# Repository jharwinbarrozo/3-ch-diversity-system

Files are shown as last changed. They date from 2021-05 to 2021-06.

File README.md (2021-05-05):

This is an Arduino code for a Wemos D1 board (ESP8266 chip), coupled to 3 LM1881 video sync separators, and a MAX4545 video switch.
Compared to the popular RSSI-based systems, the advantages a video-based diversity are:
- No need to open the receivers to get the RSSI [Receiver Signal Strength indication] signals. You just have to plug in your different receivers, and they can be of different types.
- There is no need to calibrate the RSSi signals of the different receivers (this is often the tricky part).
- It is also frequent to get a strongly distorted image, while the RSSI is high.
- When the reception level is low (flying far for instance), some receivers have RSSI close to zero, although the image is still viewable. In that case an RSSI-based system is not really efficient.

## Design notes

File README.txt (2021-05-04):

l1m          = Top layer
l2m          = Bottom layer
ss1          = Top silkscreen
sm1          = Top soldermask
sm2          = Bottom soldermask
outline      = Board outline
drill        = Plated holes Excellon file
drillnpt     = Non-Plated holes Excellon file
XYRS.csv     = Parts placement file
pcb.cad      = PCBWeb Project file

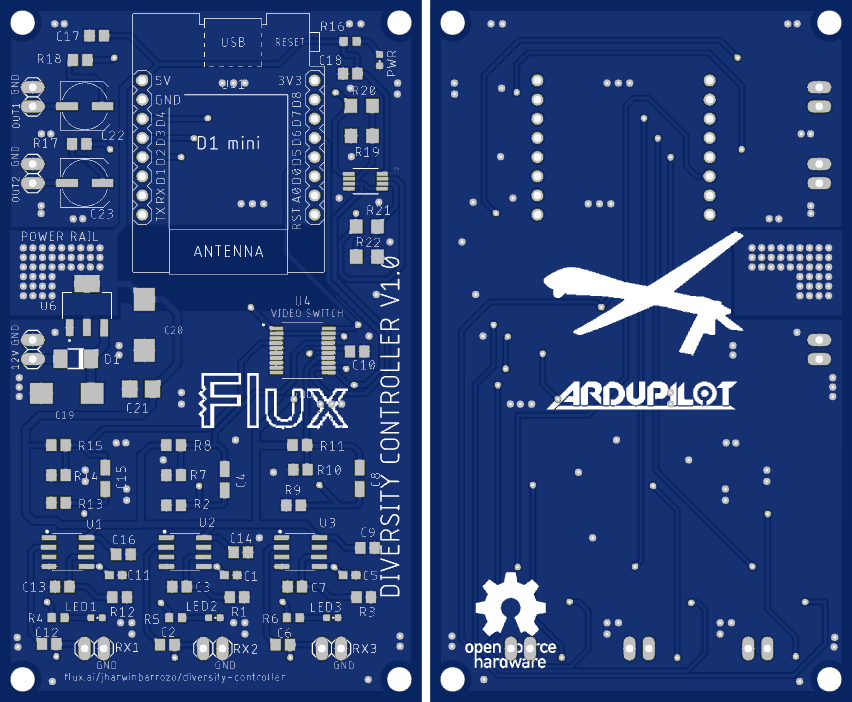
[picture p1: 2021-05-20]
board-preview.png

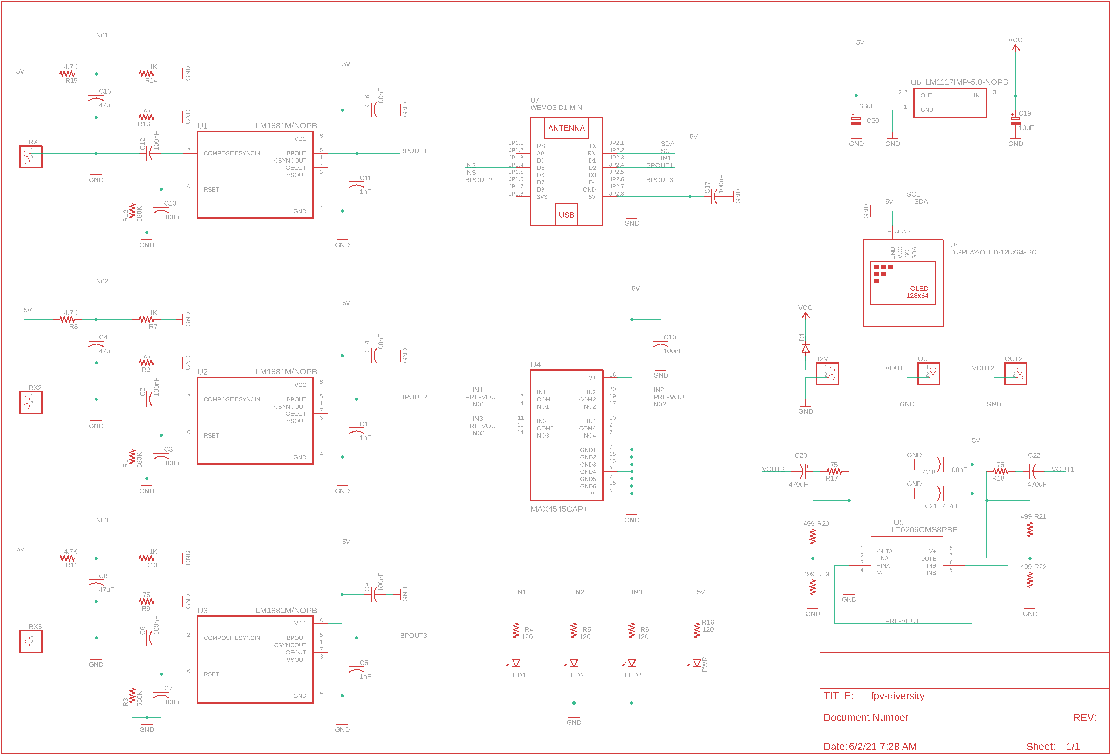
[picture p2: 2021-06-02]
fpv-diversity.png

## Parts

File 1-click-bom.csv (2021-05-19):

References | Qty | Description | Manufacturer | MPN | Digikey | Mouser | RS | Newark | Farnell
LED1, LED2, LED3 | 3 | SMD LED GREEN 0603 | Broadcom | HSMG-C190 | 516-1425-1-ND | 630HSMGC190 | 450985 |  | 2497374
12V, OUT1, OUT2, RX1, RX2, RX3 | 6 | PIN HEADER VERT 2 POS |  | M20-9990246 | 952-2262-ND | 855M209990246 | 7457065 |  | 1022247
C2, C3, C6, C7, C9, C10, C12, C13, C14, C16, C17, C18 | 12 | 100nF 0805 X7R | AVX | 08053C104KAT2A | 311-1140-6-ND | 603CC805KRX7R9BB104 | 6197992 |  | 3019949
C19 | 1 | 10uF 35V Tantalum 7343 | Vishay | 293D106X0035D2TE3 | 718-1046-6-ND | 74293D106X0035D2TE3 | 1360314 |  | 2777998
R7, R10, R14 | 3 | 1K 0805 | Yageo | RC0805JR-071KL | 311-1.00KCRCT-ND | 603RC0805FR071KL | 7409063 |  | 2303550
C1, C5, C11 | 3 | 1nF 0603 X7R | Yageo | CC0603KRX7R9BB102 | 399-1082-6-ND | 603CC603KRX7R9BB102 | 2644551 |  | 1414608
C20 | 1 | 33uF tantalum 7343 | Vishay | 293D336X9010D2TE3 | 478-4111-1-ND | 74293D336X9016D2TE3 | 6844089 |  | 1754190
R8, R11, R15 | 3 | 4.7K 0805 | Vishay | CRCW08054K70FKEA | P16893CT-ND | 667ERJP6WF4701V | 7217801 |  | 2253928
C21 | 1 | 4.7uf tantalum 3528 | Vishay | 293D475X9010B2TE3 | 718-1147-6-ND | 74293D475X9025B2TE3 | 6844130 |  | 1754215
R4, R5, R6, R16 | 4 | 120 0603 | KOA Speer | SG73P1JTTD1200F | 311-120HRDKR-ND | 603RC0603FR07120RL | 566406 |  | 2134805
C22, C23 | 2 | 470uF SMD,6.3x7.7mm Aluminum Electrolytic | Panasonic | EEEFTA471XAP | P15094TR-ND | 667EEEFTA471XAP |  |  | 2065963
C4, C8, C15 | 3 | 47uF SMD TANTALUM 3216 | AVX | F931A476KAA | 478-9009-1-ND | 581TLJA476M010R0600 | 1442515 |  | 1658411
R19, R20, R21, R22 | 4 | 499 1206 | Panasonic | ERA8AEB4990V | P499BCDKR-ND | 667ERA8AEB4990V | 8280926 |  | 2095153
R1, R3, R12 | 3 | 680K 0805 | TE Connectivity | CRGCQ0805F680K | A129783CT-ND | 667ERJP06F6803V | 1062967 |  | 2861556
R2, R9, R13, R17, R18 | 5 | 75 0805 | TE Connectivity | CRG0805F75R | A126386CT-ND | 603RC0805FR0775RL | 8667480 |  | 3496096
U6 | 1 | 5V Voltage Regulator |  | LM1117IMP-5.0-NOPB | LM1117IMP-5.0/NOPBDKR-ND | 926LM1117IMP5.0NOPB | 5358641 |  | 3122018
U1, U2, U3 | 3 | Video Sync Separator 8-SOIC 0 to 70 |  | LM1881M/NOPB | LM1881M/NOPB-ND | 926LM1881M/NOPB | 5361237 |  | 3006923
U5 | 1 | LT6206CMS8PBF |  | LT6206CMS8PBF | LT6206CMS8#PBF-ND | 584LT6206CMS8#PBF
U4 | 1 | Video Switch IC 4 Channel 20-SSOP |  | MAX4545CAP+ | MAX4545CAP+-ND | 700MAX4545CAP | 1897119 |  | 2518608
U$1 | 1 | WEMOS D1 mini: Mini Wi-Fi Board based on ESP-8266 device |  | WEMOS-D1-MINI
PWR | 1 | SMD LED RED 0603 | Everlight | 19-217/R6C-AL1M2VY/3T | 516-1420-1-ND | 630HSMHC190 | 7166570P |  | 1610883
D1 | 1 | Schottky Barrier Diodes SMA(DO-214AC) | Vishay | SS14-E3/5AT | SS14-E3/5ATGICT-ND | 625SS14E3/5AT | 5431588 |  | 2780103

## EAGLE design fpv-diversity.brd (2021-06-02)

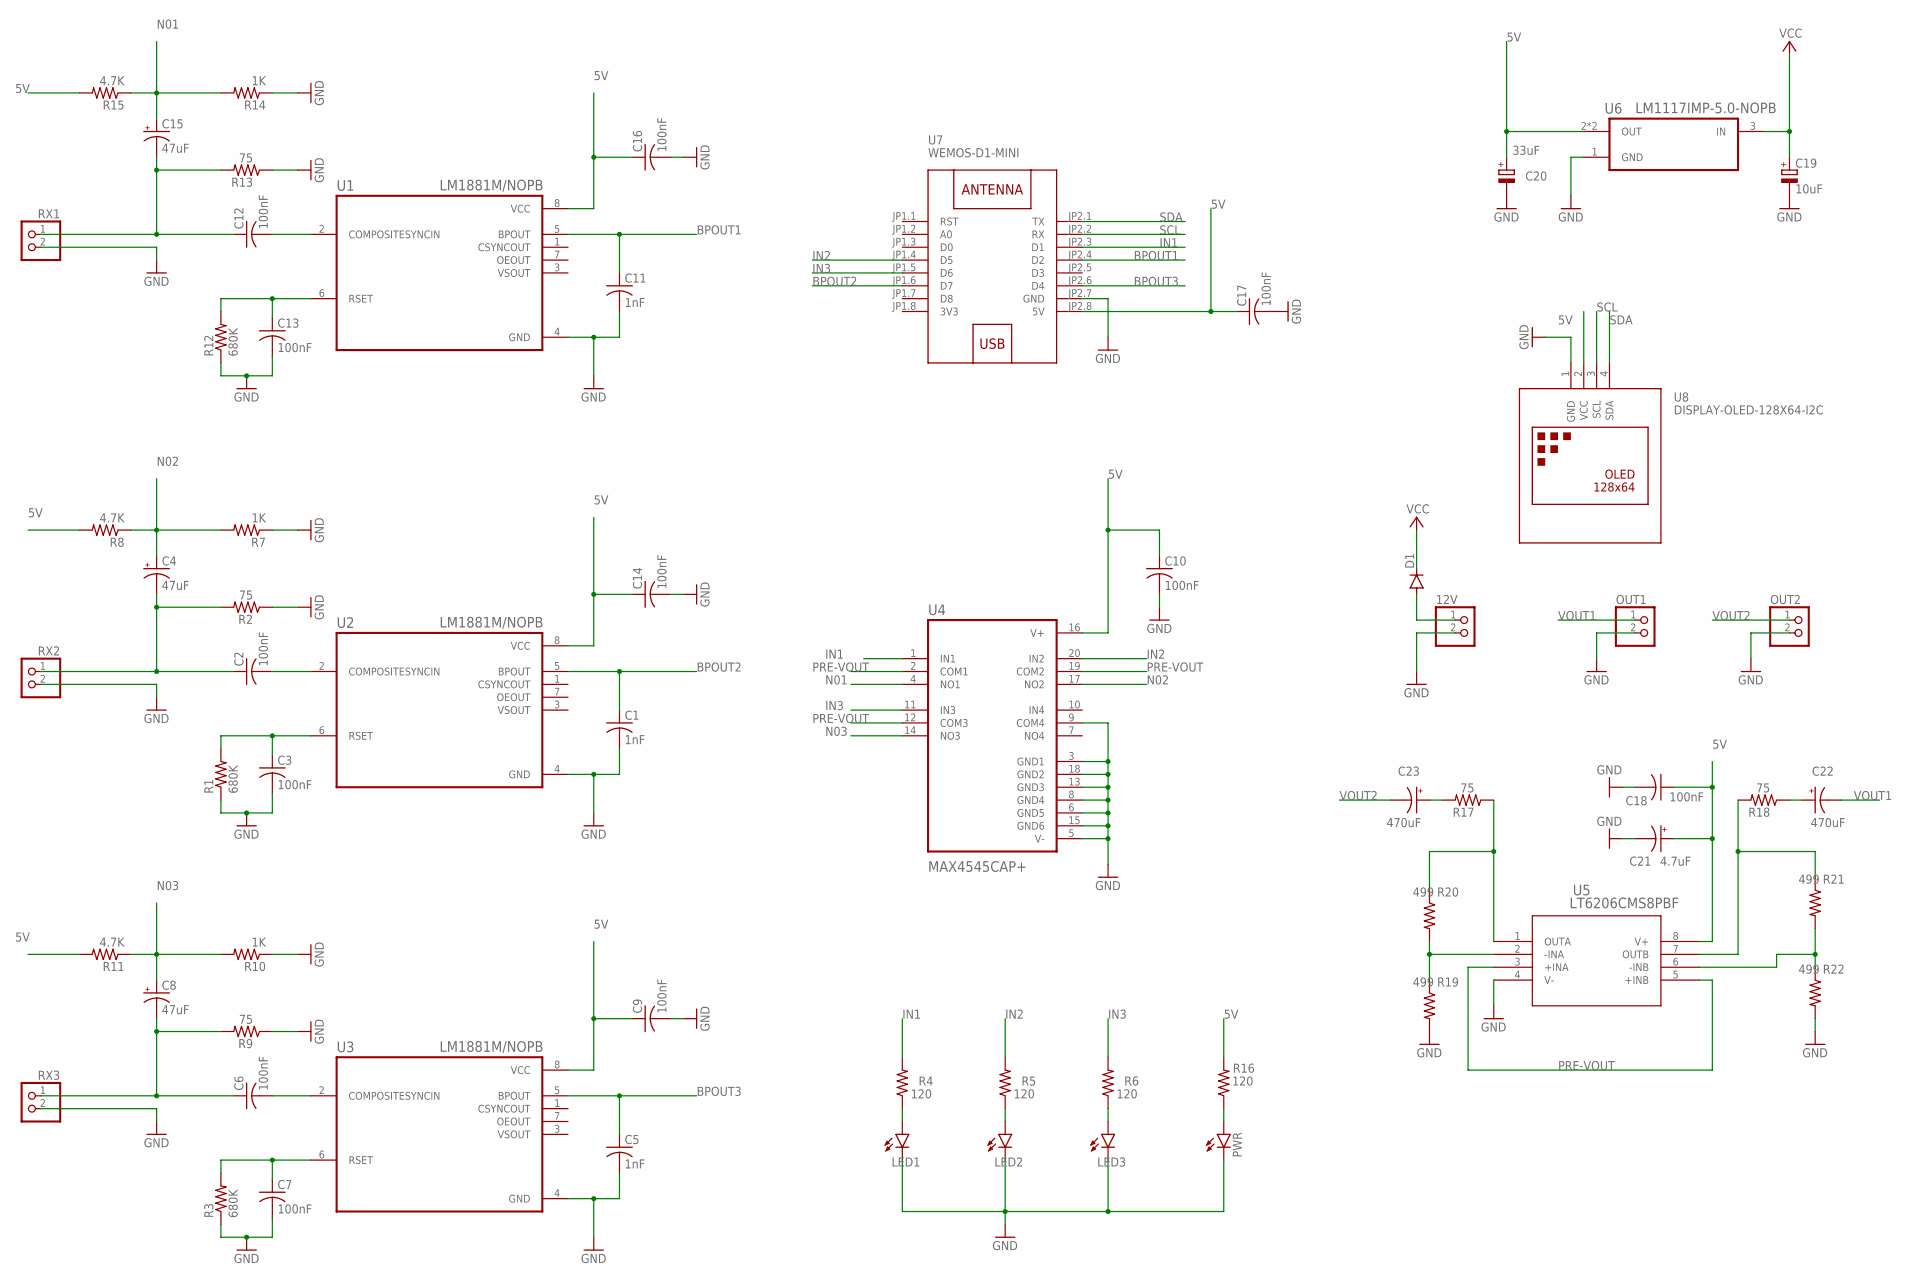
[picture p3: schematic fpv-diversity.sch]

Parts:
12V: PINHD-1X2; 1X02
C1, C5, C11: 1nF; C0603
C2, C3, C6, C7, C9, C10, C12, C13, C14, C16, C17, C18: 100nF; C0805
C4, C8, C15: 47uF; CT3216
C19: 10uF; D/7343-31W
C20: 33uF; D/7343-31W
C21: 4.7uF; CT3528
C22, C23: 470uF; UD-6,3X7,7_NICHICON
D1: DIODE-DO-214AC; DO-214AC
LED1, LED2, LED3: LEDCHIPLED_0603; CHIPLED_0603
OUT1, OUT2: PINHD-1X2; 1X02
PWR: LEDCHIPLED_0603; CHIPLED_0603
R1, R3, R12: 680K; R0805
R2, R9, R13, R17, R18: 75; R0805
R4, R5, R6, R16: 120; R0603
R7, R10, R14: 1K; R0805
R8, R11, R15: 4.7K; R0805
R19, R20, R21, R22: 499; R1206
RX1, RX2, RX3: PINHD-1X2; 1X02
U1, U2, U3: LM1881M/NOPB; SOIC127P599X175-8N
U4: MAX4545CAP+; SOP65P777X199-20N
U5: LT6206CMS8PBF; MSOP-8_MS
U6: LM1117IMP-5.0-NOPB; SOT230P700X180-4N
U7: WEMOS-D1-MINI
U8: DISPLAY-OLED-128X64-I2C

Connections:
3V3: U7.JP1.8 (3V3)
5V: C9.1, C10.1, C14.1, C16.1, C17.1, C18.1, C20.+, C21.+, R8.2, R11.2, R15.2, R16.2, U1.8 (VCC), U2.8 (VCC), U3.8 (VCC), U4.16 (V+), U5.8 (V+), U6.2 (OUT), U6.4 (OUT), U7.JP2.8 (5V), U8.2 (VCC)
BPOUT1: C11.1, U1.5 (BPOUT), U7.JP2.4 (D2)
BPOUT2: C1.1, U2.5 (BPOUT), U7.JP1.6 (D7)
BPOUT3: C5.1, U3.5 (BPOUT), U7.JP2.6 (D4)
GND: 12V.2, C1.2, C3.2, C5.2, C7.2, C9.2, C10.2, C11.2, C13.2, C14.2, C16.2, C17.2, C18.2, C19.-, C20.-, C21.-, LED1.C, LED2.C, LED3.C, OUT1.2, OUT2.2, PWR.C, R1.1, R2.1, R3.1, R7.1, R9.1, R10.1, R12.1, R13.1, R14.1, R19.2, R22.2, RX1.2, RX2.2, RX3.2, U1.4 (GND), U2.4 (GND), U3.4 (GND), U4.3 (GND1), U4.5 (V-), U4.6 (GND5), U4.8 (GND4), U4.9 (COM4), U4.13 (GND3), U4.15 (GND6), U4.18 (GND2), U5.4 (V-), U6.1 (GND), U7.JP2.7 (GND), U8.1 (GND)
IN1: R4.2, U4.1 (IN1), U7.JP2.3 (D1)
IN2: R5.2, U4.20 (IN2), U7.JP1.4 (D5)
IN3: R6.2, U4.11 (IN3), U7.JP1.5 (D6)
N01: C15.+, R14.2, R15.1, U4.4 (NO1)
N02: C4.+, R7.2, R8.1, U4.17 (NO2)
N03: C8.+, R10.2, R11.1, U4.14 (NO3)
unnamed: C7.1, R3.2, U3.6 (RSET)
unnamed: C3.1, R1.2, U2.6 (RSET)
unnamed: C2.2, U2.2 (COMPOSITESYNCIN)
unnamed: PWR.A, R16.1
unnamed: C6.2, U3.2 (COMPOSITESYNCIN)
unnamed: 12V.1, D1.A
unnamed: LED1.A, R4.1
unnamed: LED2.A, R5.1
unnamed: LED3.A, R6.1
unnamed: C13.1, R12.2, U1.6 (RSET)
unnamed: C12.2, U1.2 (COMPOSITESYNCIN)
unnamed: R19.1, R20.2, U5.2 (-INA)
unnamed: R18.2, R21.1, U5.7 (OUTB)
unnamed: R21.2, R22.1, U5.6 (-INB)
unnamed: R17.1, R20.1, U5.1 (OUTA)
unnamed: C22.+, R18.1
unnamed: C23.+, R17.2
PRE-VOUT: U4.2 (COM1), U4.12 (COM3), U4.19 (COM2), U5.3 (+INA), U5.5 (+INB)
SCL: U7.JP2.2 (RX), U8.3 (SCL)
SDA: U7.JP2.1 (TX), U8.4 (SDA)
VCC: C19.+, D1.C, U6.3 (IN)
VID1: C12.1, C15.-, R13.2, RX1.1
VID2: C2.1, C4.-, R2.2, RX2.1
VID3: C6.1, C8.-, R9.2, RX3.1
VOUT1: C22.-, OUT1.1
VOUT2: C23.-, OUT2.1

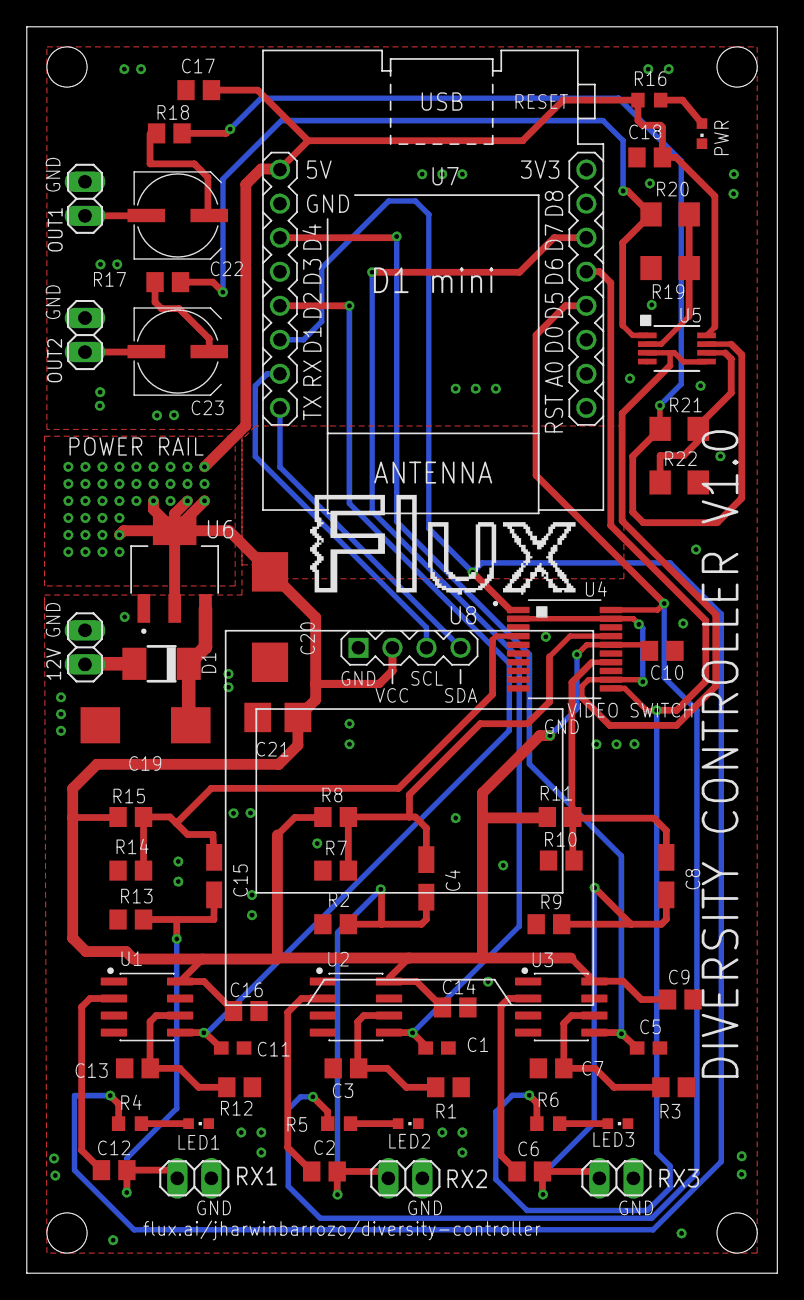
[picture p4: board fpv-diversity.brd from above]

Board: 2 copper layers, 56.0 x 93.0 mm, 64 parts (0 on the bottom side), 37 nets.

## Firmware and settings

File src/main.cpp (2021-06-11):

// 3 channel Video Diversity Controller v1.1
// selects the best video signal, based on the detection
// of line sync. pulses (coming from using LM1881 chpis).
// The souce with the most 'regular' pulses (in the last few hundered lines)
// is chosen.
//
// Hardware:
//    - Wemos D1 mini clone (ESP8266) running at 160Mhz
//    - Video switch: Max4545
//      (allows to commute 4 sources -- but code is here for 3 sources)
//    - 3 LM1881, to generate the line sync. pulses
//
// https://randomnerdtutorials.com/esp8266-pinout-reference-gpios/
// ====================================================================

#include <Arduino.h>
#include <ESP8266WiFi.h>
#include "user_interface.h"
#include <SPI.h>
#include <Wire.h>
#include <Adafruit_GFX.h>
#include <Adafruit_SSD1306.h>
#include <Adafruit_I2CDevice.h>

#define ENABLED_OLED
//#define ENABLED_SERIAL_DEBUG

#ifdef ENABLED_OLED
const String PROJECT_NAME_LN1 = "3-CH Diversity";
const String PROJECT_NAME_LN2 = "Controller ";
const String VERSION = "v1.2";
const String CREATOR = "github/jharwinbarrozo";
const int I2C_DISPLAY_ADDRESS = 0x3C;
#define SCREEN_WIDTH 128 // OLED display width, in pixels
#define SCREEN_HEIGHT 64 // OLED display height, in pixels

// flux_logo, 128x64px
const unsigned char fluxLogo [] PROGMEM = {
	0x00, 0x00, 0x00, 0x00, 0x00, 0x00, 0x00, 0x00, 0x00, 0x00, 0x00, 0x00, 0x00, 0x00, 0x00, 0x00, 
	0x00, 0x00, 0x00, 0x00, 0x00, 0x00, 0x00, 0x00, 0x00, 0x00, 0x00, 0x00, 0x00, 0x00, 0x00, 0x00, 
	0x00, 0x1f, 0xff, 0xff, 0xff, 0xff, 0xff, 0xff, 0xff, 0xff, 0xff, 0xff, 0xff, 0xff, 0xf8, 0x00, 
	0x00, 0x80, 0x00, 0x00, 0x00, 0x00, 0x00, 0x00, 0x00, 0x00, 0x00, 0x00, 0x00, 0x00, 0x01, 0x00, 
	0x02, 0x00, 0x00, 0x00, 0x00, 0x00, 0x00, 0x00, 0x00, 0x00, 0x00, 0x00, 0x00, 0x00, 0x00, 0x40, 
	0x04, 0x00, 0x00, 0x00, 0x00, 0x00, 0x00, 0x00, 0x00, 0x00, 0x00, 0x00, 0x00, 0x00, 0x00, 0x20, 
	0x08, 0x00, 0x00, 0x00, 0x00, 0x00, 0x00, 0x00, 0x00, 0x00, 0x00, 0x00, 0x00, 0x00, 0x00, 0x10, 
	0x00, 0x00, 0x00, 0x00, 0x00, 0x00, 0x00, 0x00, 0x00, 0x00, 0x00, 0x00, 0x00, 0x00, 0x00, 0x00, 
	0x10, 0x00, 0x00, 0x00, 0x00, 0x00, 0x00, 0x00, 0x00, 0x00, 0x00, 0x00, 0x00, 0x00, 0x00, 0x08, 
	0x00, 0x00, 0x00, 0x00, 0x00, 0x00, 0x00, 0x00, 0x00, 0x00, 0x00, 0x00, 0x00, 0x00, 0x00, 0x00, 
	0x00, 0x00, 0x00, 0x00, 0x00, 0x00, 0x00, 0x00, 0x00, 0x00, 0x00, 0x00, 0x00, 0x00, 0x00, 0x00, 
	0x20, 0x00, 0x00, 0x00, 0x00, 0x00, 0x00, 0x00, 0x00, 0x00, 0x00, 0x00, 0x00, 0x00, 0x00, 0x04, 
	0x20, 0x0f, 0xff, 0xff, 0xff, 0x07, 0xf8, 0x38, 0x79, 0xc8, 0xf3, 0x13, 0x9e, 0x04, 0x88, 0x04, 
	0x20, 0x08, 0x00, 0x00, 0x01, 0x06, 0x18, 0x22, 0x40, 0x09, 0x03, 0x10, 0x11, 0x04, 0xc8, 0x04, 
	0x20, 0x08, 0x00, 0x00, 0x01, 0x04, 0x08, 0x22, 0x41, 0x09, 0x02, 0x90, 0x10, 0x84, 0x88, 0x04, 
	0x20, 0x08, 0x00, 0x00, 0x01, 0x04, 0x08, 0x22, 0x70, 0xc9, 0x32, 0x13, 0x90, 0x84, 0xa8, 0x04, 
	0x20, 0x08, 0x00, 0x00, 0x01, 0x04, 0x08, 0x22, 0x40, 0x49, 0x02, 0x50, 0x10, 0x84, 0x88, 0x04, 
	0x20, 0x08, 0x00, 0x00, 0x01, 0x04, 0x08, 0x22, 0x40, 0x49, 0x02, 0x30, 0x11, 0x04, 0x98, 0x04, 
	0x20, 0x08, 0x1f, 0xff, 0xff, 0x04, 0x08, 0x38, 0x79, 0xc8, 0xf2, 0x33, 0xde, 0x04, 0x88, 0x04, 
	0x20, 0x08, 0x10, 0x00, 0x00, 0x04, 0x08, 0x00, 0x00, 0x00, 0x00, 0x00, 0x00, 0x00, 0x00, 0x04, 
	0x20, 0x08, 0x10, 0x00, 0x00, 0x04, 0x08, 0x00, 0x00, 0x00, 0x00, 0x00, 0x00, 0x00, 0x00, 0x04, 
	0x20, 0x0c, 0x10, 0x00, 0x00, 0x04, 0x08, 0x00, 0x00, 0x00, 0x00, 0x00, 0x00, 0x00, 0x00, 0x04, 
	0x20, 0x06, 0x10, 0x00, 0x00, 0x04, 0x08, 0x00, 0x00, 0x00, 0x00, 0x00, 0x00, 0x00, 0x00, 0x04, 
	0x20, 0x06, 0x10, 0x00, 0x00, 0x04, 0x08, 0x3f, 0x80, 0x03, 0xf8, 0x7f, 0x80, 0x07, 0xf8, 0x04, 
	0x20, 0x04, 0x10, 0x00, 0x00, 0x04, 0x08, 0x20, 0x80, 0x02, 0x08, 0x20, 0xc0, 0x08, 0x30, 0x04, 
	0x20, 0x08, 0x10, 0x00, 0x00, 0x04, 0x08, 0x20, 0x80, 0x02, 0x08, 0x30, 0x40, 0x18, 0x20, 0x04, 
	0x20, 0x10, 0x10, 0x00, 0x00, 0x04, 0x08, 0x20, 0x80, 0x02, 0x08, 0x10, 0x20, 0x10, 0x60, 0x04, 
	0x20, 0x10, 0x10, 0x00, 0x00, 0x04, 0x08, 0x20, 0x80, 0x02, 0x08, 0x08, 0x30, 0x20, 0x40, 0x04, 
	0x20, 0x08, 0x1f, 0xff, 0xff, 0x04, 0x08, 0x20, 0x80, 0x02, 0x08, 0x0c, 0x10, 0x60, 0x80, 0x04, 
	0x20, 0x04, 0x00, 0x00, 0x01, 0x04, 0x08, 0x20, 0x80, 0x02, 0x08, 0x04, 0x08, 0x41, 0x80, 0x04, 
	0x20, 0x02, 0x00, 0x00, 0x01, 0x04, 0x08, 0x20, 0x80, 0x02, 0x08, 0x02, 0x04, 0x81, 0x00, 0x04, 
	0x20, 0x04, 0x00, 0x00, 0x01, 0x04, 0x08, 0x20, 0x80, 0x02, 0x08, 0x01, 0x05, 0x82, 0x00, 0x04, 
	0x20, 0x08, 0x00, 0x00, 0x01, 0x04, 0x08, 0x20, 0x80, 0x02, 0x08, 0x01, 0x03, 0x06, 0x00, 0x04, 
	0x20, 0x10, 0x00, 0x00, 0x01, 0x04, 0x08, 0x20, 0x80, 0x02, 0x08, 0x00, 0x80, 0x04, 0x00, 0x04, 
	0x20, 0x10, 0x1f, 0xff, 0xff, 0x04, 0x08, 0x20, 0x80, 0x02, 0x08, 0x00, 0x40, 0x08, 0x00, 0x04, 
	0x20, 0x08, 0x10, 0x00, 0x00, 0x04, 0x08, 0x20, 0x80, 0x02, 0x08, 0x00, 0x60, 0x10, 0x00, 0x04, 
	0x20, 0x04, 0x10, 0x00, 0x00, 0x04, 0x08, 0x20, 0x80, 0x02, 0x08, 0x00, 0x20, 0x10, 0x00, 0x04, 
	0x20, 0x02, 0x10, 0x00, 0x00, 0x04, 0x08, 0x20, 0x80, 0x02, 0x08, 0x00, 0x20, 0x30, 0x00, 0x04, 
	0x20, 0x04, 0x10, 0x00, 0x00, 0x04, 0x08, 0x20, 0x80, 0x02, 0x08, 0x00, 0x60, 0x10, 0x00, 0x04, 
	0x20, 0x08, 0x10, 0x00, 0x00, 0x04, 0x08, 0x20, 0x80, 0x04, 0x08, 0x00, 0x40, 0x08, 0x00, 0x04, 
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
};

// Declaration for an SSD1306 display connected to I2C (SDA, SCL pins)
#define OLED_RESET     -1 // Reset pin # (or -1 if sharing Arduino reset pin)
Adafruit_SSD1306 display(SCREEN_WIDTH, SCREEN_HEIGHT, &Wire, OLED_RESET);
#endif

#define N 500

//Pin connected to the LM1881 sync outputs (INPUTS for mcu)
#define PIN_SyncA D2 // BPOUT1
#define PIN_SyncB D7 // BPOUT2
#define PIN_SyncC D4 // BPOUT3

//Pin connected to the MAX4545 (switch) pin that selects the desired source (OUTPUT for MCU)
#define PIN_selectA D1 // IN1
#define PIN_selectB D5 // IN2
#define PIN_selectC D6 // IN3

// keyword "Volatile" means that this variable may be changed by a routine called by some interrupt.
volatile unsigned long lastA; // Time of the last sync signal
volatile unsigned long lastB; // Time of the last sync signal
volatile unsigned long lastC; // Time of the last sync signal

unsigned long now;

#define t0 63
const long unsigned mus = t0 * N; // Period to update the selected source, in micro sec.
const long unsigned mis = mus / 1000; // same as above, in milli sec.

#define sourceA 0
#define sourceB 1
#define sourceC 2
int selected;
unsigned long lastMillis;

//-----------------------------------------------------------------
class ExpAverage {
  private:
    volatile float x;
    const float a, b;
  public:
    ExpAverage(int n): a(1.0f / n), b(1.0f - a) { // exponential average over the ~n previous values
      x = 0.0f;
    }
    inline float getAverage() {
      return x;
    }
    void addValue(unsigned long v) {
      x = a * v + b * x;
    }
};

//------------------------------------------------------------------------
ExpAverage A(N), B(N), C(N);// Average video line duration for the different sources
#if defined(ENABLED_OLED) || defined(ENABLED_SERIAL_DEBUG)
ExpAverage AA(N), BB(N), CC(N);// Average video line duration for the different sources
#endif
//------------------------------------------------------------------------

//------------------------------------------------------------------------
const int CLEAR = (1 << PIN_selectA) + (1 << PIN_selectB) + (1 << PIN_selectC);
int Bin[3] = {1 << PIN_selectA , 1 << PIN_selectB, 1 << PIN_selectC};
inline void SwitchTo(int s) {
  if (selected != s) {
    selected = s;
    GPOC = CLEAR;//Clear PIN_selectA, PIN_selectB and PIN_selectC simultaneously
    GPOS = Bin[s];
  }
}
//------------------------------------------------------------------------

//------------------------------------------------------------------------
class PeriodicTask {
  private:
    os_timer_t myTimer;
    int t;
  public:
    //---------------------------------------------------------------------
    static void DoTask(void *pArg) {//static needed here, because below we want to pass a pointer to this member function
      const unsigned long  now = micros();
      if (now - lastA > mus) {
        //if no pulse was received since last update, put the value 'mus' into the average
        //... so, if no pulse is received at all (disconnected cable, etc.à, the average line duration will be 'mus=N*64' (very large compared to 64) so this
        // source will not be selected.
        A.addValue(mus); lastA = now;
      }
      if (now - lastB > mus) B.addValue(mus), lastB = now;
      if (now - lastC > mus) C.addValue(mus), lastC = now;

      //Get the average deviation (from ~63 micro seconds) of the line durations
      const float avA = A.getAverage();
      const float avB = B.getAverage();
      const float avC = C.getAverage();

      if (avB < avA) {
        //The best is B or C
        if (avC < avB)
        {
          SwitchTo(sourceC);
        }
        else {
          SwitchTo(sourceB);
        }

      } else {//The best is A or C
        if (avA < avC)
          SwitchTo(sourceA); else {
            SwitchTo(sourceC);
          }
      }
    }
    //----------------------------------------------------------------
    PeriodicTask () {
      os_timer_setfn(&myTimer, DoTask, NULL);
    }
    void Start(int t, bool repeat = true) {
      os_timer_arm(&myTimer, t, repeat);
    }
};
PeriodicTask T;

//----------------------------Count-------------------------------------
IRAM_ATTR void CountA() {
  const unsigned long  now = micros();
  const long period = now - lastA;
  lastA = now;
  A.addValue(abs(period - t0));
#if defined(ENABLED_OLED) || defined(ENABLED_SERIAL_DEBUG)
  AA.addValue(period);
#endif
}
IRAM_ATTR void CountB() {
  const unsigned long now = micros();
  const long period = now - lastB;
  lastB = now;
  B.addValue(abs(period - t0));
#if defined(ENABLED_OLED) || defined(ENABLED_SERIAL_DEBUG)
  BB.addValue(period);
#endif
}
IRAM_ATTR void CountC() {
  const unsigned long now = micros();
  const long period = now - lastC;
  lastC = now;
  C.addValue(abs(period - t0));
#if defined(ENABLED_OLED) || defined(ENABLED_SERIAL_DEBUG)
  CC.addValue(period);
#endif
}
//-----------------------------Setup------------------------------------

void setup() {
 WiFi.mode(WIFI_OFF);
 WiFi.forceSleepBegin();

#ifdef ENABLED_SERIAL_DEBUG
  Serial.begin(115200);
  Serial.println("Serial Debug is active.");
  delay(2000);
#endif

#ifdef ENABLED_OLED
// To change the default i2c pins (SDA D2, SCL D1) to TX (gpio1) and RX (gpio3)
// Wire.begin(sda int, scl int);
  Wire.begin(1,3);

  // SSD1306_SWITCHCAPVCC = generate display voltage from 3.3V internally
  if(!display.begin(SSD1306_SWITCHCAPVCC, I2C_DISPLAY_ADDRESS)) {
    for(;;); // Don't proceed, loop forever
  }
  // Display start up..
  display.clearDisplay();
  display.setTextSize(1.2);
  display.setTextColor(SSD1306_WHITE);
  display.drawRect(0,0,128,36,WHITE);
  display.setCursor(20,9);  
  display.print(PROJECT_NAME_LN1);
  display.setCursor(20,19);  
  display.print(PROJECT_NAME_LN2);
  display.print(VERSION);
  display.setCursor(0,42);
  display.println("Designed by: ");
  display.setCursor(0,52);
  display.print(CREATOR);
  display.display(); delay(3000);
  display.clearDisplay();
  display.drawBitmap(0, 0, fluxLogo, 128, 64, SSD1306_WHITE);
  display.display();
#endif

  lastA = 0; // Time of the last signal on sensor A
  lastB = 0; // Time of the last signal on sensor B
  lastC = 0; // Time of the last signal on sensor C

  pinMode(PIN_SyncA, INPUT);
  pinMode(PIN_SyncB, INPUT);
  pinMode(PIN_SyncC, INPUT);

  pinMode(PIN_selectA, OUTPUT);
  pinMode(PIN_selectB, OUTPUT);
  pinMode(PIN_selectC, OUTPUT);

  selected = sourceB;
  //Some blinking to start
  for (int i = 0; i < 3; i++) {
    SwitchTo(sourceA); delay(250);
    SwitchTo(sourceB); delay(250);
    SwitchTo(sourceC); delay(250);
  }
  //Declare 3 interrupts, to measure the duration between horizontal sync. pulses
  //on the 3 sources
  attachInterrupt(PIN_SyncA, CountA, FALLING);
  attachInterrupt(PIN_SyncB, CountB, FALLING);
  attachInterrupt(PIN_SyncC, CountC, FALLING);

  T.Start(mis, true); //Start the process that updates the selected source every 'mis' milliseconds (timer-based)
}
//-----------------------------------------------------------------

void loop() {
#ifdef ENABLED_OLED
    const float avAA = AA.getAverage();
    const float avBB = BB.getAverage();
    const float avCC = CC.getAverage();

    //Prints some debug information to the serial output, every 1000 milli sec.
    display.clearDisplay();

    display.setTextColor(SSD1306_WHITE);
    display.setTextSize(1);
    display.setCursor(6,6);
    display.print("ACTIVE");

    // 3 small boxes with border
    display.drawCircle(48, 9, 3, SSD1306_WHITE);
    display.drawCircle(57, 9, 3, SSD1306_WHITE);
    display.drawCircle(66, 9, 3, SSD1306_WHITE);

    // Box wrapper with border
    display.drawRect(0, 0, 75, 52, SSD1306_WHITE);
    
    display.setTextSize(3);
    display.setCursor(5,13);
    display.print("v");
    display.setTextSize(4);
    display.setCursor(24,18);
    display.print("R");
    display.setCursor(49,18);
    display.print("X");

    //solid white wrapper for the huge 1,2,3
    display.fillRect(80, 0, 50, 52, SSD1306_WHITE);
      if (selected == sourceA) {
        //triangle shape to cut the solid box
        display.fillTriangle(118, 0, 128, 0, 128, 10, SSD1306_BLACK);
        display.fillCircle(48, 9, 3, SSD1306_WHITE); // fill for small box
        display.setTextSize(6);
        display.setCursor(89,6);
        display.setTextColor(SSD1306_BLACK);
        display.print("1");
      }
      if (selected == sourceB) {
        //triangle shape to cut the solid box
        display.fillTriangle(118, 0, 128, 0, 128, 10, SSD1306_BLACK);
        display.fillCircle(57, 9, 3, SSD1306_WHITE); // fill for small box
        display.setTextSize(6);
        display.setCursor(89,6);
        display.setTextColor(SSD1306_BLACK);
        display.print("2");
      }
      if (selected == sourceC) {
        //triangle shape to cut the solid box
        display.fillTriangle(118, 0, 128, 0, 128, 10, SSD1306_BLACK);
        display.fillCircle(66, 9, 3, SSD1306_WHITE); // fill for small box
        display.setTextSize(6);
        display.setCursor(89,6);
        display.setTextColor(SSD1306_BLACK);
        display.print("3");
      }
    // Average values of rx1, rx2, rx3 at the bottom
    display.setTextSize(1);
    display.setTextColor(SSD1306_WHITE);
    // RX1
    display.setCursor(3,56);
    display.print(avAA);
    //RX2
    display.setCursor(50,56);
    display.print(avBB);
    //RX3
    display.setCursor(100,56);
    display.print(avCC);
    display.display();
#endif

#ifdef ENABLED_SERIAL_DEBUG
    if (millis() > lastMillis + 1000) {
    lastMillis = millis();
    //Prints some debug information to the serial output, every 1000 milli sec.
    Serial.print("Time: "); Serial.println(millis());
    if (selected == sourceA)     Serial.print("=>");
    Serial.print("RX1:");
    const float avA = A.getAverage();
    Serial.print(avA);
    const float avAA = AA.getAverage();
    Serial.print(" - "); Serial.println(avAA);

    if (selected == sourceB)     Serial.print("=>");
    Serial.print("RX2:");
    const float avB = B.getAverage();
    Serial.print(avB);
    const float avBB = BB.getAverage();
    Serial.print(" - "); Serial.println(avBB);

    if (selected == sourceC)     Serial.print("=>");
    Serial.print("RX3:");
    const float avC = C.getAverage();
    Serial.print(avC);
    const float avCC = CC.getAverage();
    Serial.print(" - "); Serial.println(avCC);
    Serial.println("");
}
#endif
  yield();
}

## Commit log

2021-05-05 Gerber and bom files update
    [copper_bottom.gbr, copper_top.gbr, drill_1_16.xln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]
2021-05-05 Bom format update
    [fpv-diversity.csv, fpv-diversity.tsv]
2021-05-05 Move drill file into GerberFiles directory
    [drill_1_16.xln]
2021-05-05 pcb routes correction
    [fpv-diversity.sch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]
2021-05-06 Add eagle pcb file
    [fpv-diversity.brd]
2021-05-06 add eda,type,pcb_path
2021-05-15 PCB updates
    [fpv-diversity.brd, fpv-diversity.sch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]
2021-05-17 .brd cleanup
    [fpv-diversity.brd, fpv-diversity.sch]
2021-05-18 more updates
    [fpv-diversity.brd, fpv-diversity.sch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]
2021-05-19 bom file and path updates
    [1-click-bom.csv, fpv-diversity.tsv]
2021-06-02 board gerber updates
    [fpv-diversity.brd, fpv-diversity.sch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]
2022-02-24 arranged the content of folders
    [fpv-diversity.sch]

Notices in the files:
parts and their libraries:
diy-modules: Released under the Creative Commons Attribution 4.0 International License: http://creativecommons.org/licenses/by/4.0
